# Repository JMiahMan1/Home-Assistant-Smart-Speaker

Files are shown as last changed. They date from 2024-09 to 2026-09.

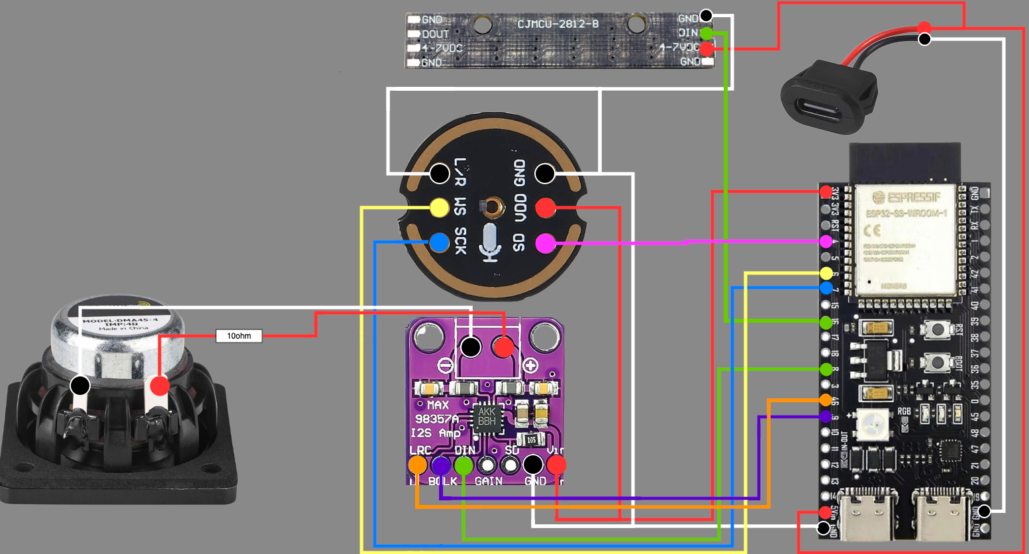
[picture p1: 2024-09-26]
schem/media_player_schematic_gry-bg.png

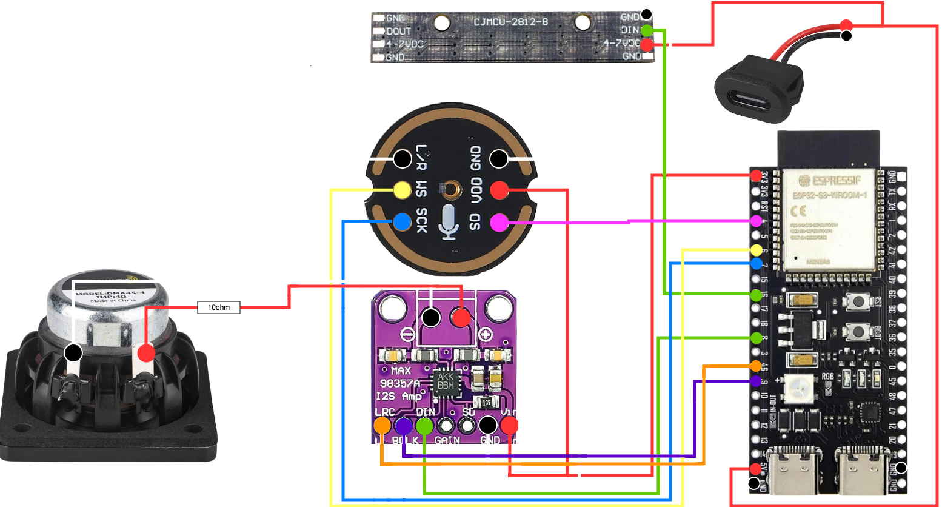
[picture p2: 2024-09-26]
schem/media_player_schematic.png

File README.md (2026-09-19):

# Smart Speaker ESPHome Configuration

ESP32-S3 smart speaker that works as both a Music Assistant player and a Home
Assistant voice satellite.

* Audio in: INMP441 I2S microphone
* Audio out: MAX98357A I2S amplifier
* Wake word: micro_wake_word (Hey Jarvis)
* LEDs: WS2812 status LED and WS2812 light bar

## Build

```bash
./setup.sh                                  # compile
./setup.sh --upload smart-speaker.local     # compile + OTA
./setup.sh --upload /dev/cu.usbmodem1434101 # compile + serial
./setup.sh --clean                          # wipe venv and build artifacts
```

The script creates a virtualenv, installs the pinned ESPHome version, and runs
`esphome compile`. Nothing else is required.

### ESPHome version is pinned

`setup.sh` pins ESPHome to 2026.3.3. External I2S amplifiers on the ESP32-S3
regressed when the legacy I2S driver was removed in 2026.4.0
([esphome#16369](https://github.com/esphome/esphome/issues/16369), still open).
Do not bump this without testing audio output.

## Audio chain

```
media_pipeline       -> resampler -> mixer input (media)        \
                                                                 mixer -> MAX98357A
announcement_pipeline -> resampler -> mixer input (announcement) /
```

Things that matter here:

* Do not put LRCLK on GPIO46. It is a strapping pin with a weak internal
  pull-down, and it corrupts the word select clock badly enough that the
  MAX98357A amplifies garbage. The symptom is loud static that survives every
  software change, including muting the digital stream. LRCLK is on GPIO5.
* The mixer does not resample. Music Assistant streams arbitrary sample rates
  (44.1kHz is common) into a 48kHz chain, so each source needs a resampler in
  front of it. Removing them produces badly distorted audio.
* `timeout: never` on the speaker and both mixer inputs. A finite timeout
  releases the I2S bus between chunks, and reacquiring it clicks on every
  playback edge.

Music ducks 20dB while the assistant is speaking and is restored in `on_end`,
once the assistant has fully stopped.

## Volume

Volume is controlled through the `media_out` entity, which is what Home
Assistant, Music Assistant, voice intents and any physical buttons all talk to.
Use `media_player.volume_up`, `volume_down` and `volume_set` for buttons.

`volume_max` is a remap rather than a clamp. The reported volume still reads 0
to 100%, but it is rescaled into `volume_min..volume_max` before reaching the
speaker, so `volume_max` is the real output ceiling. It applies even to a volume
restored from flash, which is why setting `volume_initial` on its own does
nothing once the device has saved a volume.

The i2s speaker maps volume onto a 100 entry logarithmic table where index 0 is
silence and index 99 is 0dB. The bottom of the range is compressed, so small
percentages are much quieter than they look. 50% is roughly -25dB, not half
volume.

`volume_max` is 100%, which is unity. There is no digital gain above it, so more
output has to come from the MAX98357A GAIN pin: 100k to GND gives 15dB, tied to
GND 12dB, floating 9dB (the default), tied to VDD 6dB, 100k to VDD 3dB.

The Mute switch uses `media_player.mute` and `unmute` rather than setting a
volume, so the level survives a mute and comes back on unmute. Do not put a
`volume_set` there: the switch restores to OFF on boot, so its unmute action
runs every boot and would pin the volume to whatever it named.

For voice control ("set volume to 50%"), expose the `media_out` entity to Assist
in Home Assistant and give the device an area. Without that, the intent has no
target to resolve.

## LED driver split

Enabling audio on the ESP32-S3 leaves only one RMT TX channel free, which is not
enough to drive two WS2812 strips the usual way. So the two strips use different
drivers:

* Light bar (GPIO16): `esp32_rmt_led_strip` with DMA, using the one RMT channel.
* Status LED (GPIO48): `single_ws2812`, a bit-bang driver in `SRC/` that uses no
  RMT channel.

## Notes

Earlier versions of this project vendored esp-tflite-micro, esp-nn, esp-dsp,
mdns and multipart-parser into `my_components/`, with patches and a two-pass
PlatformIO build. None of that is needed now. Stock ESPHome declares those
dependencies itself, pinned, and resolves them through the IDF component
manager. If you disable `IDF_COMPONENT_MANAGER`, IDF ignores
`src/idf_component.yml` and the build fails on missing headers.

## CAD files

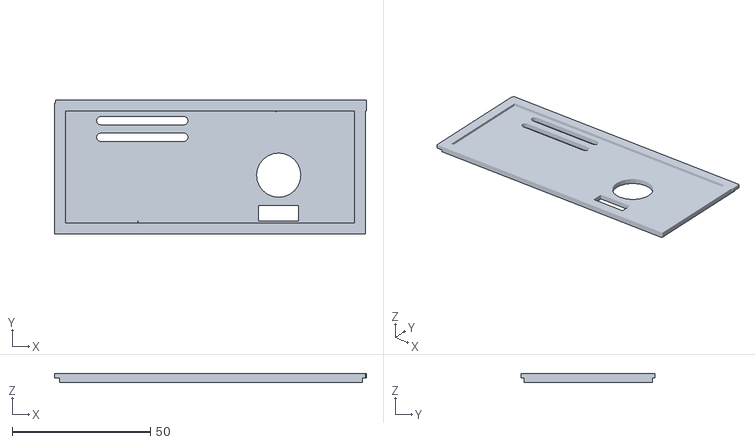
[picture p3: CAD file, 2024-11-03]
3D Print/Speaker-Back-Panel.stl
112.8 x 48.5 x 3.10

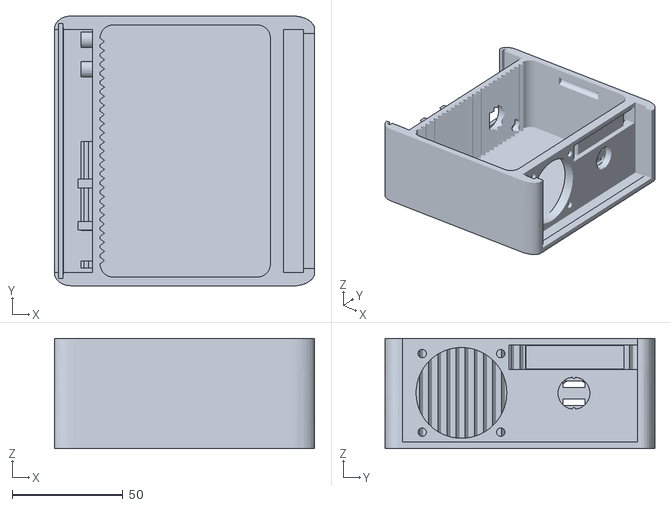
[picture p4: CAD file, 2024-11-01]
3D Print/Speaker-Enclosure.stl
117.7 x 122.0 x 49.8

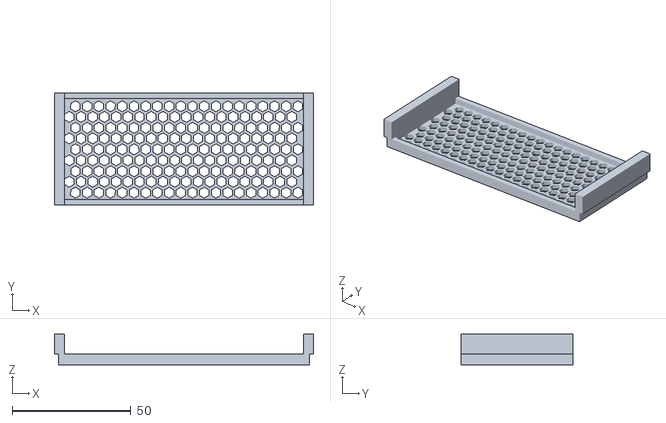
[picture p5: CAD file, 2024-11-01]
3D Print/Speaker-Grille.stl
109.1 x 47.2 x 13.0

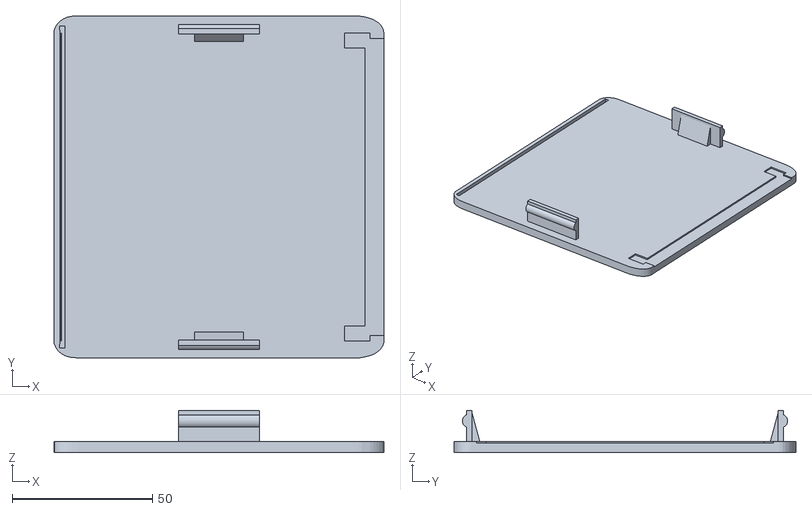
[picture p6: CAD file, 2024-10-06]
3D Print/Speaker-Enclosure-Lid.stl
117.7 x 122.0 x 15.0

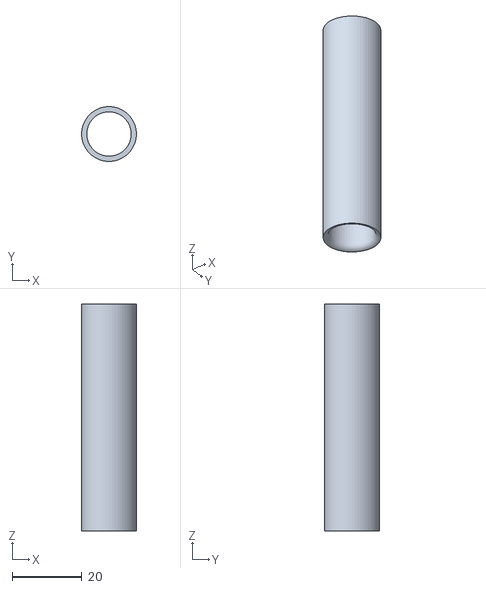
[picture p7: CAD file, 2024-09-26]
3D Print/Port.stl
15.7 x 15.7 x 65.0

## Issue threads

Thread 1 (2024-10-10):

Led Cutout

trentsmart, 2024-10-10:
Just maybe a suggestion, maybe not though. With the little led strip that I got the little mounting holes were on the bottom and not the top lol so i had to flip the strip over and it made the DIN side on the other side so I tried as best I could to make the same rectangle hole as you did on the left, on the right this time. Great work btw.

JMiahMan1, 2024-10-17:
I know there are different configurations and even the spacing of the holes can be different from order to order so I have just removed the posts altogether and used a little bit of hot glue to keep it in place. I might create a tab on one end and then snug it just underneath the speaker, we'll see how it works. I warned everyone it was a work in progress lol. Thanks for the feedback though.

JMiahMan1, 2024-10-17:
I tink with removing the posts this has been fixed, unless I misunderstood, so I am going to close this out. Thanks again for your feedback!

Closed 2024-11-03.

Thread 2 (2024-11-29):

step/f3d files?

spitfire, 2024-11-29:
Hey, can you post step/f3d files? With someone's help I might finally get around to learn Autodesk Fusion (or something similar) and maybe modify the model to fit my needs?
i.e. I've bought LED strips that are very similar, but not only do they have different spacing between the holes, but also they're a bit longer. There are probably other things I'd try, like adding ethernet to the build;)

JMiahMan1, 2025-04-01:
I don't have Autodesk Fusion but I used [TinkCad.com ](https://www.tinkercad.com/) to modify these files. You can import the stl files into TinkerCad and edit them yourself, or learn a much more advanced CAD software, either way normally the STL files are enough.

Closed 2025-04-01.

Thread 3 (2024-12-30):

Compile Error

switchtower, 2024-12-30:
Tried my best to resolve this, but unfortunately, I can't.  I was hoping you could shed some light on this issue, you appear to be more versed in esphome_audio than I.  I was looking at the original yaml file and I too would like this to act as a media player, but can't get your code to compile.  Here is the error, the only thing I've changed in the yaml file is the api_key and the wifi config:

```
INFO_ ESPHome 2024.12.2
INFO Reading configuration /config/test.yaml...
INFO Updating https://github.com/gnumpi/esphome_audio@dev-next
INFO Detected timezone 'America/New_York'
WARNING GPIO46 is a strapping PIN and should only be used for I/O with care.
Attaching external pullup/down resistors to strapping pins can cause unexpected failures.
See https://esphome.io/guides/faq.html#why-am-i-getting-a-warning-about-strapping-pins
INFO Generating C++ source...
INFO Updating https://github.com/espressif/esp-adf.git@v2.5
INFO Updating submodules (components/esp-adf-libs, components/esp-sr) for https://github.com/espressif/esp-adf.git@v2.5
INFO Updating https://github.com/espressif/esp-tflite-micro@v1.3.1
INFO Updating https://github.com/espressif/esp-nn@v1.1.0
INFO Compiling app...
Processing smart-speaker2 (board: esp32-s3-devkitc-1; framework: espidf; platform: https://github.com/pioarduino/platform-espressif32.git#51.03.07)
--------------------------------------------------------------------------------
Library Manager: Installing bblanchon/ArduinoJson @ 6.18.5
INFO Installing bblanchon/ArduinoJson @ 6.18.5
Unpacking  [####################################]  100%  
Library Manager: ArduinoJson@6.18.5 has been installed!
INFO ArduinoJson@6.18.5 has been installed!
Library Manager: Installing kahrendt/ESPMicroSpeechFeatures @ 1.1.0
INFO Installing kahrendt/ESPMicroSpeechFeatures @ 1.1.0
Unpacking  [####################################]  100%
Library Manager: ESPMicroSpeechFeatures@1.1.0 has been installed!
INFO ESPMicroSpeechFeatures@1.1.0 has been installed!
Library Manager: Installing esphome/noise-c @ 0.1.6
INFO Installing esphome/noise-c @ 0.1.6
Unpacking  [####################################]  100%
Library Manager: noise-c@0.1.6 has been installed!
INFO noise-c@0.1.6 has been installed!
Library Manager: Resolving dependencies...
INFO Resolving dependencies...
Library Manager: Installing esphome/libsodium @ 1.10018.4
INFO Installing esphome/libsodium @ 1.10018.4
Unpacking  [####################################]  100%  
Library Manager: libsodium@1.10018.4 has been installed!
INFO libsodium@1.10018.4 has been installed!
/config/.esphome/platformio/packages/framework-espidf Already Patched: yes
HARDWARE: ESP32S3 240MHz, 320KB RAM, 8MB Flash
 - framework-espidf @ 3.50105.0 (5.1.5)
 - tool-cmake @ 3.21.3
 - tool-esptoolpy @ 4.8.1
 - tool-mklittlefs @ 3.2.0
 - tool-ninja @ 1.7.1
 - tool-riscv32-esp-elf-gdb @ 12.1.0+20221002
 - tool-xtensa-esp-elf-gdb @ 12.1.0+20221002
 - toolchain-esp32ulp @ 2.35.0-20220830
 - toolchain-riscv32-esp @ 12.2.0+20230208
 - toolchain-xtensa-esp32s3 @ 12.2.0+20230208
Reading CMake configuration...
-- Found Git: /usr/bin/git (found version "2.39.5")
-- git rev-parse returned 'fatal: not a git repository (or any parent up to mount point /)
Stopping at filesystem boundary (GIT_DISCOVERY_ACROSS_FILESYSTEM not set).'
-- The C compiler identification is GNU 12.2.0
-- The CXX compiler identification is GNU 12.2.0
-- The ASM compiler identification is GNU
-- Found assembler: /config/.esphome/platformio/packages/toolchain-xtensa-esp32s3/bin/xtensa-esp32s3-elf-gcc
-- Detecting C compiler ABI info
-- Detecting C compiler ABI info - done
-- Check for working C compiler: /config/.esphome/platformio/packages/toolchain-xtensa-esp32s3/bin/xtensa-esp32s3-elf-gcc - skipped
-- Detecting C compile features
-- Detecting C compile features - done
-- Detecting CXX compiler ABI info
-- Detecting CXX compiler ABI info - done
-- Check for working CXX compiler: /config/.esphome/platformio/packages/toolchain-xtensa-esp32s3/bin/xtensa-esp32s3-elf-g++ - skipped
-- Detecting CXX compile features
-- Detecting CXX compile features - done
-- Building ESP-IDF components for target esp32s3
Processing 1 dependencies:
[1/1] idf (5.1.5)
-- Configuring incomplete, errors occurred!
See also "/config/.esphome/build/smart-speaker2/.pioenvs/smart-speaker2/CMakeFiles/CMakeOutput.log".

fatal: not a git repository (or any parent up to mount point /)
Stopping at filesystem boundary (GIT_DISCOVERY_ACROSS_FILESYSTEM not set).
CMake Error at /config/.esphome/platformio/packages/framework-espidf/tools/cmake/build.cmake:266 (message):
  Failed to resolve component 'esp_adc_cal'.
Call Stack (most recent call first):
  /config/.esphome/platformio/packages/framework-espidf/tools/cmake/build.cmake:302 (__build_resolve_and_add_req)
  /config/.esphome/platformio/packages/framework-espidf/tools/cmake/build.cmake:309 (__build_expand_requirements)
  /config/.esphome/platformio/packages/framework-espidf/tools/cmake/build.cmake:603 (__build_expand_requirements)
  /config/.esphome/platformio/packages/framework-espidf/tools/cmake/project.cmake:604 (idf_build_process)
  CMakeLists.txt:3 (project)

========================= [FAILED] Took 25.79 seconds =========================
```

switchtower, 2024-12-30:
https://github.com/gnumpi/esphome_audio/issues/74#issuecomment-2550330719

Closed 2024-12-30.

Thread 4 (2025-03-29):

Error when copiling

rednet1, 2025-03-29:
Reading CMake configuration...
-- Found Git: /usr/bin/git (found version "2.39.5")
-- git rev-parse returned 'fatal: not a git repository (or any parent up to mount point /)
Stopping at filesystem boundary (GIT_DISCOVERY_ACROSS_FILESYSTEM not set).'
-- The C compiler identification is GNU 12.2.0
-- The CXX compiler identification is GNU 12.2.0
-- The ASM compiler identification is GNU
-- Found assembler: /data/cache/platformio/packages/toolchain-xtensa-esp32s3/bin/xtensa-esp32s3-elf-gcc
-- Detecting C compiler ABI info
-- Detecting C compiler ABI info - done
-- Check for working C compiler: /data/cache/platformio/packages/toolchain-xtensa-esp32s3/bin/xtensa-esp32s3-elf-gcc - skipped
-- Detecting C compile features
-- Detecting C compile features - done
-- Detecting CXX compiler ABI info
-- Detecting CXX compiler ABI info - done
-- Check for working CXX compiler: /data/cache/platformio/packages/toolchain-xtensa-esp32s3/bin/xtensa-esp32s3-elf-g++ - skipped
-- Detecting CXX compile features
-- Detecting CXX compile features - done
-- Building ESP-IDF components for target esp32s3
Processing 1 dependencies:
[1/1] idf (5.1.5)
-- Configuring incomplete, errors occurred!
See also "/data/build/smart-speaker/.pioenvs/smart-speaker/CMakeFiles/CMakeOutput.log".

fatal: not a git repository (or any parent up to mount point /)
Stopping at filesystem boundary (GIT_DISCOVERY_ACROSS_FILESYSTEM not set).
CMake Error at /data/cache/platformio/packages/framework-espidf@src-6e6cd5244a43bdfe453daac50cfe73b6/tools/cmake/build.cmake:266 (message):
  Failed to resolve component 'esp_adc_cal'.
Call Stack (most recent call first):
  /data/cache/platformio/packages/framework-espidf@src-6e6cd5244a43bdfe453daac50cfe73b6/tools/cmake/build.cmake:302 (__build_resolve_and_add_req)
  /data/cache/platformio/packages/framework-espidf@src-6e6cd5244a43bdfe453daac50cfe73b6/tools/cmake/build.cmake:309 (__build_expand_requirements)
  /data/cache/platformio/packages/framework-espidf@src-6e6cd5244a43bdfe453daac50cfe73b6/tools/cmake/build.cmake:603 (__build_expand_requirements)
  /data/cache/platformio/packages/framework-espidf@src-6e6cd5244a43bdfe453daac50cfe73b6/tools/cmake/project.cmake:604 (idf_build_process)
  CMakeLists.txt:3 (project)

========================== [FAILED] Took 6.59 seconds ==========================

JMiahMan1, 2025-04-01:
Make sure everything is updated to the latest version, also take a look at the output log referenced:
"/data/build/smart-speaker/.pioenvs/smart-speaker/CMakeFiles/CMakeOutput.log"

AndreyShpilevoy, 2025-05-13:
@rednet1 you can try to check my post in another Issue: https://github.com/JMiahMan1/Home-Assistant-Smart-Speaker/issues/5#issuecomment-2878179597

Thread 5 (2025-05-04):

cant compile

comet424, 2025-05-04:
hi so copy and pasted the code.. and updated the API key

but it wont compile  i get this error now

INFO ESPHome 2025.4.1
INFO Reading configuration /config/esphome/smart-speaker-1.yaml...
INFO Updating https://github.com/gnumpi/esphome_audio@dev-next
INFO Detected timezone 'America/Toronto'
Failed config

light.esp32_rmt_led_strip: [source /config/esphome/smart-speaker-1.yaml:487]
  platform: esp32_rmt_led_strip
  rgb_order: GRB
  pin: GPIO48
  num_leds: 1

  This feature is not available for the IDF framework version 5.
  rmt_channel: 0
  chipset: WS2812
  name: Status LED
  id: led
  disabled_by_default: True
  icon: mdi:led-on
  default_transition_length: 0s
  effects:

AndreyShpilevoy, 2025-05-13:
Didn't tested yet, but was able to build.
You need to add the following lines
```
    version: 4.4.8
    platform_version: 5.4.0
```
 to
```
esp32:
  board: esp32-s3-devkitc-1
  framework:
    type: esp-idf
    version: 4.4.8
    platform_version: 5.4.0
```

and also replace
```
      ref: dev-next
```
with
```
      ref: pull/79/head
```
in
```
external_components:
  - source:
      type: git
      url: https://github.com/gnumpi/esphome_audio
      ref: pull/79/head
    components: [adf_pipeline, i2s_audio]
    refresh: 0s
```

AndreyShpilevoy, 2025-05-15:
I couldn't make it fully work. Volume control was broken for me, no matter what I tried.
So I changed it a bit in my fork. Please check if you are interested: [fork](https://github.com/AndreyShpilevoy/Home-Assistant-Smart-Speaker)

I will not make a PR from my branch to this one because I have way too many changes in how the LED indication works.
But if @jmiahman thinks that it's good enough, I can create it. No Problem.

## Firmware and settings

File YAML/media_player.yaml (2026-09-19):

substitutions:
  name: smart-speaker
  friendly_name: smart-speaker
  api_key: !secret api_key

####################################################################
#### change the micro wake word to be used on the line below   #####
####      options are okay_nabu, hey_jarvis, alexa             #####
####################################################################
  micro_wake_word_model: hey_jarvis
####################################################################

  # Phases of the Voice Assistant
  # IDLE: The voice assistant is ready to be triggered by a wake-word
  voice_assist_idle_phase_id: '1'
  # LISTENING: The voice assistant is ready to listen to a voice command (after being triggered by the wake word)
  voice_assist_listening_phase_id: '2'
  # THINKING: The voice assistant is currently processing the command
  voice_assist_thinking_phase_id: '3'
  # REPLYING: The voice assistant is replying to the command
  voice_assist_replying_phase_id: '4'
  # NOT_READY: The voice assistant is not ready
  voice_assist_not_ready_phase_id: '10'
  # ERROR: The voice assistant encountered an error
  voice_assist_error_phase_id: '11'
  # MUTED: The voice assistant is muted and will not reply to a wake-word
  voice_assist_muted_phase_id: '12'

  #pins
  i2s_out_lrclk_pin: GPIO5 # LRC on Max98357 (moved off GPIO46, a strapping pin)
  i2s_out_bclk_pin: GPIO9  # BCLK on Max98357
  i2s_in_lrclk_pin: GPIO6 # WS on INMP441
  i2s_in_bclk_pin: GPIO7 # SLK on INMP441
  led_pin: GPIO48 # on-board LED
  led_bar_pin: GPIO16 # Light Bar LED
  speaker_pin: GPIO8 # DIN on Max98357
  mic_pin: GPIO4 # SD on INMP441

esphome:
  name: ${name}
  friendly_name: ${friendly_name}
  min_version: 2026.2.0

  on_boot:
      priority: 600
      then:
        # Run the script to refresh the LED status
        - script.execute: control_led
        # - output.turn_off: set_low_speaker
        # If after 30 seconds, the device is still initializing (It did not yet connect to Home Assistant), turn off the init_in_progress variable and run the script to refresh the LED status
        - delay: 30s
        - if:
            condition:
              lambda: return id(init_in_progress);
            then:
              - lambda: id(init_in_progress) = false;
              - script.execute: control_led
esp32:
  board: esp32-s3-devkitc-1
  framework:
    type: esp-idf
    sdkconfig_options:
      # need to set a s3 compatible board for the adf-sdk to compile
      # board specific code is not used though
      CONFIG_ESP32_S3_BOX_BOARD: "y"
      CONFIG_ESP32_WIFI_STATIC_RX_BUFFER_NUM: "16"
      # 240MHz: FLAC decode + mixer + I2S@48k need CPU headroom, 160MHz causes underruns
      CONFIG_ESP_DEFAULT_CPU_FREQ_MHZ_240: "y"
      CONFIG_ESP_DEFAULT_CPU_FREQ_MHZ: "240"
      CONFIG_ESP32_WIFI_DYNAMIC_RX_BUFFER_NUM: "512"
      CONFIG_TCPIP_RECVMBOX_SIZE: "512"

      CONFIG_TCP_SND_BUF_DEFAULT: "65535"
      CONFIG_TCP_WND_DEFAULT: "512000"
      CONFIG_TCP_RECVMBOX_SIZE: "512"

      CONFIG_ESP32S3_DEFAULT_CPU_FREQ_240: "y"
      CONFIG_ESP32S3_DATA_CACHE_64KB:      "y"
      CONFIG_ESP32S3_DATA_CACHE_LINE_64B:  "y"

      # Fix for connection failures (TTS/Audio)
      CONFIG_LWIP_MAX_SOCKETS: "32"
      CONFIG_MBEDTLS_EXTERNAL_MEM_ALLOC: "y"
psram:
  mode: quad
  speed: 80MHz

# external_components:
#   - source:
#       type: git
#       url: https://github.com/gnumpi/esphome_audio
#       ref: dev-next
# micro_wake_word now comes from stock ESPHome, which declares esp-tflite-micro,
# esp-nn and esp-micro-speech-features as pinned managed components itself. The
# vendored fork was a 2025.12.1 copy and no longer compiles against this core.
external_components:
  - source: ../SRC
    components: [single_ws2812]


#     refresh: 0s


api:
  encryption:
    key: !secret api_key
  on_client_connected:
    - lambda: |-
        id(api_connection) = true;
    - script.execute: control_led
  on_client_disconnected:
    - lambda: |-
        id(api_connection) = false;
    - script.execute: control_led

ota:
  - platform: esphome

logger:
  hardware_uart: USB_SERIAL_JTAG

improv_serial:

mdns:

wifi:
  ssid: !secret wifi_ssid
  password: !secret wifi_password
  power_save_mode: none

  ap:
    ssid: ${name}
    password: esp32123
  on_connect:
    - lambda: |-
        id(wifi_connection) = true;
    - script.execute: control_led
  on_disconnect:
    - lambda: |-
        id(wifi_connection) = false;
    - script.execute: control_led

captive_portal:

web_server:

time:
  - platform: homeassistant
    id: ha_time
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

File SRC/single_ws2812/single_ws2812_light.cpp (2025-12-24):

#include "single_ws2812_light.h"

namespace esphome {
namespace single_ws2812 {

void SingleWS2812Light::setup() {
    ESP_LOGI("single_ws2812", "Setting up Single WS2812 LED on pin %d", pin_);
    gpio_reset_pin((gpio_num_t)pin_);
    gpio_set_direction((gpio_num_t)pin_, GPIO_MODE_OUTPUT);
}

light::LightTraits SingleWS2812Light::get_traits() {
    auto traits = light::LightTraits();
    traits.set_supported_color_modes({light::ColorMode::RGB});
    return traits;
}

void SingleWS2812Light::write_state(light::LightState *state) {
    float red, green, blue;
    state->current_values_as_rgb(&red, &green, &blue);

    // Convert to 0-255
    uint8_t r = (uint8_t)(red * 255);
    uint8_t g = (uint8_t)(green * 255);
    uint8_t b = (uint8_t)(blue * 255);

    // Disable interrupts to ensure timing
    portMUX_TYPE mux = portMUX_INITIALIZER_UNLOCKED;
    taskENTER_CRITICAL(&mux);

    // GRB Order
    send_byte(g);
    send_byte(r);
    send_byte(b);

    taskEXIT_CRITICAL(&mux);
}

void IRAM_ATTR SingleWS2812Light::send_byte(uint8_t val) {
    for (int i = 0; i < 8; i++) {
        if (val & 0x80) {
            send_one();
        } else {
            send_zero();
        }
        val <<= 1;
    }
}

void IRAM_ATTR SingleWS2812Light::send_zero() {
    set_pin_level(1);
    delay_cycles(96); 
    set_pin_level(0);
    delay_cycles(204);
}

void IRAM_ATTR SingleWS2812Light::send_one() {
    set_pin_level(1);
    delay_cycles(192);
    set_pin_level(0);
    delay_cycles(108);
}

void IRAM_ATTR SingleWS2812Light::set_pin_level(int level) {
    if (pin_ < 32) {
        if (level) {
            REG_WRITE(GPIO_OUT_W1TS_REG, 1 << pin_);
        } else {
            REG_WRITE(GPIO_OUT_W1TC_REG, 1 << pin_);
        }
    } else {
        if (level) {
            REG_WRITE(GPIO_OUT1_W1TS_REG, 1 << (pin_ - 32));
        } else {
            REG_WRITE(GPIO_OUT1_W1TC_REG, 1 << (pin_ - 32));
        }
    }
}

void IRAM_ATTR SingleWS2812Light::delay_cycles(uint32_t cycles) {
    uint32_t start = get_ccount();
    while ((get_ccount() - start) < cycles) {
        // Spin
    }
}

uint32_t IRAM_ATTR SingleWS2812Light::get_ccount() {
    uint32_t ccount;
    __asm__ __volatile__("rsr %0,ccount":"=a" (ccount));
    return ccount;
}

} // namespace single_ws2812
} // namespace esphome

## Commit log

2024-09-26 Initial commit of some files
    [Back panel.stl, Enclosure.stl, Lid.stl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]
2024-09-26 Add a schematic png file with grey background
2024-10-04 Few updates to 3D files
    [Back panel.stl, Enclosure.stl, Speaker-Back-Panel.stl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]
2024-10-04 Allow larger lightbars to fit
    [Speaker-Enclosure.stl]
2024-10-06 Create new Lid
    [Lid.stl, Speaker-Enclosure-Lid.stl]
2024-11-01 Some changes
    [Speaker-Enclosure.stl, Speaker-Grille.stl]
2024-11-01 Pull API Key from Secrets
    [Speaker-Back-Panel.stl]
2024-11-03 update back panael USB position
    [Speaker-Back-Panel.stl]
2025-12-24 An API Key fix and some new funcionality testing
    [media_player.yaml]
2026-09-19 Fix audio static, migrate to ESPHome 2026.3.3 native esp-idf build
    Move LRCLK off GPIO46 to GPIO5. GPIO46 is a strapping pin whose internal
    pull-down corrupted the word select clock, so the MAX98357A amplified
    garbage. That produced loud static immune to every software change, and
    forced volume_max down to 5% to be tolerable. On GPIO5 the same firmware
    needs 55% to be audible.
    Restore the resampler speakers ahead of the mixer. The mixer does not
    resample, so Music Assistant streaming 44.1kHz into a 48kHz chain was
    badly distorted. Set timeout: never so the I2S bus is not released and
    reacquired between chunks, and repair ducking, which never ran because
    on_start was empty and nothing restor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
    [media_player.yaml]
2026-09-19 Raise volume ceiling to unity and fix mute clobbering the level
    Use media_player.mute and unmute for the Mute switch instead of setting
    volumes. The switch restores to OFF on boot, so its unmute action ran on
    every boot and pinned the logical volume, which made volume_max changes
    look like they did nothing. Mute now preserves the level.
    Raise volume_max to 100%. Output is logical volume times volume_max, so
    with the mute bug the effective level was far below what was configured.
    100% is unity and there is no digital gain above it; more output needs
    the MAX98357A GAIN pin rewired.
    Document the volume scale, the mute behaviour and what Home Assistant
    needs in order to answer "set volume to 5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
    [media_player.yaml]
